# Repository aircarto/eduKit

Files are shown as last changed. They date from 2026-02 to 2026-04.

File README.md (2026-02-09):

# Kit Pedagogique CO2

Projet simple pour mesurer et afficher le CO2 en temps réel avec un ESP32.

## Materiel Necessaire

| Composant | Quantité |
|---|---|
| ESP32 DevKit V1 | 1 |
| Capteur CO2 SensAir S88 | 1 |
| Ecran OLED 0.96" SSD1306 I2C | 1 |
| Cables dupont | ~8 |
| Breadboard (optionnel) | 1 |

## Schema de Cablage

```
                    ESP32 DevKit
                  ┌──────────────┐
                  │              │
    OLED GND ─────┤ GND      VIN ├───── SensAir G+ (5V)
    OLED VDD ─────┤ 3V3      GND ├───── SensAir G0
                  │              │
    OLED SCK ─────┤ GPIO22       │
    OLED SDA ─────┤ GPIO21       │
                  │              │
SensAir TxD ──────┤ GPIO16 (RX2) │
SensAir RxD ──────┤ GPIO17 (TX2) │
                  │              │
                  └──────────────┘
```

### Details du Cablage

#### Ecran OLED SSD1306 (I2C)
| OLED | ESP32 |
|---|---|
| GND  | GND |
| VDD  | 3.3V  |
| SCK  | GPIO 22 (horloge I2C) |
| SDA  | GPIO 21 |

#### Capteur SensAir S88 (UART)
| SensAir | ESP32 |
|---|---|
| G0 | GND |
| G+ | 5V (VIN) |
| UART_TxD | GPIO 16 (RX2) |
| UART_RxD | GPIO 17 (TX2) |

> ⚠️ **ATTENTION**: Le capteur SensAir S88 fonctionne en **5V**, pas en 3.3V!
> Utilise la pin `VIN` de l'ESP32 (qui sort du 5V quand branché en USB).
> Les autres pins (Alarm_OC, PWM 1kHz, DVCC_out, etc.) ne sont pas utilisées.

## Commandes

```bash
# Compiler le projet
pio run

# Compiler et uploader
pio run -t upload

# Voir les logs série
pio device monitor
```

## Fonctionnement

1. **Au démarrage**: L'écran affiche "ATELIER PEDAGOGIQUE" avec une barre de progression
2. **Ensuite**: La valeur de CO2 s'affiche en gros avec un message selon le niveau:
   - **< 800 ppm**: "Air excellent" (bien aéré)
   - **800-1200 ppm**: "Correct" (acceptable)
   - **1200-1500 ppm**: "Aérer SVP!" (à surveiller)
   - **> 1500 ppm**: "AÉRER VITE!" (urgent)

## Structure du Projet

```
kit-pedagogique-co2/
├── platformio.ini          # Configuration PlatformIO
├── src/
│   └── main.cpp            # Code principal
├── lib/
│   └── SensAir_S88/        # Bibliothèque capteur CO2
│       ├── SensAir_S88.h
│       └── SensAir_S88.cpp
└── README.md               # Ce fichier
```

## Debug

Les logs série sont disponibles à 115200 bauds. Tu verras:
- Les valeurs CO2 toutes les 2 secondes
- Les erreurs de communication si le capteur n'est pas détecté

### Erreurs Communes

| Erreur | Cause probable |
|---|---|
| "Timeout" | Capteur non connecté ou mauvais câblage TX/RX |
| "Réponse invalide" | Interférence ou capteur défectueux |
| Valeurs aberrantes | Capteur en préchauffage (attendre 1-2 min) |

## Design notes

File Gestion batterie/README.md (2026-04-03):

# Edukit – V3

Cette V3 est une évolution du module d’alimentation conçu pour un kit éducatif.  

La carte est organisée en plusieurs blocs fonctionnels : une **entrée USB**, un **chargeur Li-ion TP4056**, une **protection batterie DW01A + FS8205A**, un **étage de load sharing**, puis un **convertisseur boost MT3608** qui génère le **5V final** pour alimenter le système éducatif.

Le principal problème de la **V2** était le suivant :  
le système fonctionnait lorsque l’USB était branché, mais **la batterie seule n’alimentait pas correctement le MT3608**, donc le kit ne pouvait pas fonctionner normalement en mode autonome.

La **V3** corrige ce comportement en mettant en place un vrai chemin d’alimentation cohérent entre :
- l’entrée USB,
- la batterie Li-ion,
- le bloc de partage de charge,
- et le convertisseur boost 5V.

### 1. USB input
L’alimentation arrive d’abord par le **connecteur micro-USB**.  
Quand un câble USB est branché, la ligne **VIN** fournit l’énergie au reste du système de gestion d’alimentation.

### 2. Battery charging
Le **TP4056** gère la recharge d’une **batterie Li-ion 1 cellule**.  
Quand l’USB est présent, il récupère le 5V d’entrée et recharge la batterie via sa broche **BAT**.  
Le courant de charge est défini par la résistance reliée à la broche **PROG**, et les deux LEDs associées au TP4056 permettent d’indiquer l’état de charge et la fin de charge.

### 3. Battery protection
La batterie ne part pas directement vers la sortie : elle passe d’abord par un **circuit de protection** composé du **DW01A** et du **FS8205A**.  
Ce bloc sert à sécuriser l’utilisation de la cellule Li-ion en protégeant contre :
- la surcharge,
- la décharge trop profonde,
- et les défauts de type surintensité ou court-circuit.

### 4. Load sharing
Le bloc de **load sharing** est la partie clé de cette V3.  
Son rôle est de gérer intelligemment la source d’énergie utilisée par le système.

En pratique :
- **si l’USB est branché**, le système peut être alimenté pendant que la batterie se recharge ;
- **si l’USB est retiré**, la batterie reprend automatiquement le relais.

Autrement dit, le kit peut être **utilisé et rechargé en même temps**, sans dépendre uniquement de la batterie lorsque l’USB est présent.

### 5. Step-up conversion to 5V
Après le bloc de partage de charge, l’alimentation attaque le **MT3608**.  
Ce composant est un **convertisseur boost** : il prend la tension disponible en entrée et l’élève pour produire une **sortie 5V stable**.

Autour du MT3608, on retrouve :
- l’inductance,
- la diode Schottky du boost,
- les condensateurs de filtrage,
- et le pont de résistances de feedback qui fixe la tension de sortie.

Le **5V obtenu** est ensuite envoyé vers le connecteur de sortie destiné à alimenter le système éducatif.

Cette architecture est intéressante pour un kit éducatif parce qu’elle montre, dans une seule carte, plusieurs fonctions essentielles de l’électronique embarquée :

- recharger une batterie Li-ion correctement,
- protéger la batterie,
- alimenter un système même pendant la charge,
- basculer automatiquement entre USB et batterie,
- et générer un 5V exploitable par un module externe.

La V3 n’est donc pas seulement une correction de la V2 : c’est une version plus aboutie, plus robuste et plus pédagogique.

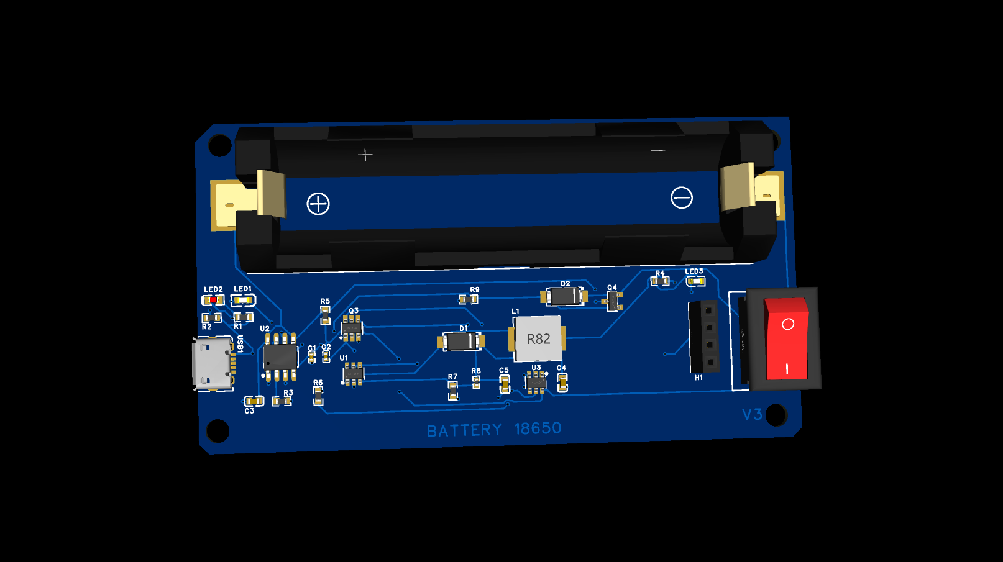
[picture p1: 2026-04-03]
Gestion batterie/3D_view.png

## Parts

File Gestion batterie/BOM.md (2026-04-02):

# BOM 

Liste des composants avec références LCSC .

| Composant | Détail  | Package | ID PCB Design | ID LCSC |
|---|---|---|---|---|
| Connecteur USB | Micro‑USB femelle, entrée charge | SMD (micro‑USB) | USB1 | C132563 |
| Résistance | 20 kΩ | 0603 | R9 | C4184 |
| Condensateur | 100 nF (découplage) | 0402 | C1, C2 | C307331 |
| Condensateur | 10 µF | 0603 | C3 | C1691 |
| Condensateur | 22 µF | 0603 | C4, C5 | C59461 |
| LED | LED bleue | 0603 | LED1 | C2987539 |
| LED | LED rouge| 0603 | LED2 | C7496810 |
| LED | LED verte | 0603 | LED3 | C2986059 |
| Résistance | 1 kΩ | 0603 | R1, R2, R4, R6 | C2907002 ||
| Résistance | 1.2 kΩ | 0603 | R3 | C2906976 |
| Résistance | 10 kΩ | 0603 | R7 | C2930027 |
| Résistance | 73.2 kΩ | 0402 | R8 | C26986 |
| Chargeur Li‑ion | TP4056 (charge 1 cellule) | ESOP-8L | U2 | C49045948 |
| MOSFET double | FS8205A (double MOSFET pour protection) | SOT‑23‑6 | Q5 | C2830320 |
| Protection Li‑ion | DW01A (IC protection 1 cellule) | SOT‑23‑6 | U3 | C351410 |
| Diode Schottky | SS34 (redressement / protection) | SMA | D1, D2 | C22448055 |
| Résistance | 100 Ω | 0603 | R5 | C2906981 |
| MOSFET P‑channel | DMP1045U‑7 | SOT‑23 | Q4 | C177033 |
| Support batterie | Support/porte‑pile 18650 | THT / mécanique | BT1 | C2988620 |
| Interrupteur | Slide switch (ON/OFF) | SMD | SW1 | C6917318 |
| Inductance | 22 µH (boost) | SMD 7x6.6mm | L1 | C177244 |
| Convertisseur boost | MT3608 (step‑up) | SOT‑23‑6 | U1 | C84817 |
| Header | Header femelle 1×4, pas 2.54 mm | THT 2.54 mm | H1 | C5116530 |

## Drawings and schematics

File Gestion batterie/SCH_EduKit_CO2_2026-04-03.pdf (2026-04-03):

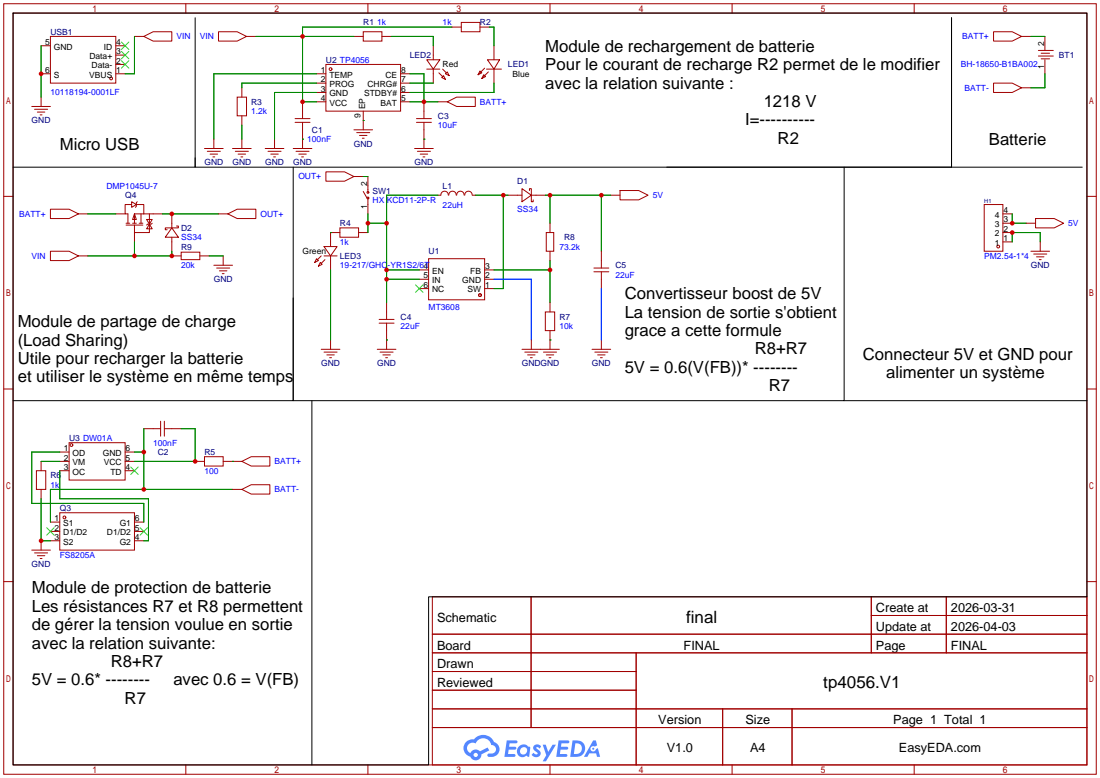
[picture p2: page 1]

Module de rechargement de batterie
Pour le courant de recharge R2 permet de le modifier
Blue
avec la relation suivante :

Convertisseur boost de 5V
La tension de sortie s'obtient
grace a cette formule

Module de partage de charge
(Load Sharing)
Utile pour recharger la batterie
et utiliser le système en même temps

Connecteur 5V et GND pour
alimenter un système

GND
Module de protection de batterie
Les résistances R7 et R8 permettent
de gérer la tension voulue en sortie
avec la relation suivante:
5V = 0.6* -------- avec 0.6 = V(FB)

Schematic | final | Create at | 2026-03-31

Update at | 2026-04-03

Board | FINAL | Page | FINAL
Drawn | | tp4056.V1
Reviewed

Version | Size | Page 1 Total 1
V1.0 | A4 | EasyEDA.com

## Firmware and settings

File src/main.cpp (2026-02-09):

/**
 * ============================================
 *         KIT PEDAGOGIQUE CO2
 * ============================================
 *
 * Materiel:
 *   - Raspberry Pi Pico 2 W
 *   - Capteur CO2 SensAir S88
 *   - Ecran OLED 0.96" SSD1306 (I2C, bicolore jaune/bleu)
 *
 * Cablage:
 *   OLED:
 *     - GND  -> GND
 *     - VDD  -> 3.3V
 *     - SCL  -> GPIO 5 (I2C0 SCL)
 *     - SDA  -> GPIO 4 (I2C0 SDA)
 *
 *   SensAir S88:
 *     - G0       -> GND
 *     - G+       -> VBUS (5V)
 *     - UART_TxD -> GPIO 1 (UART0 RX)
 *     - UART_RxD -> GPIO 0 (UART0 TX)
 *
 * Note: Le capteur S88 utilise le protocole Modbus RTU a 9600 bauds.
 *
 * OLED bicolore: les 16 premiers pixels (y 0-15) sont jaunes,
 * le reste (y 16-63) est bleu. Le layout est optimise en consequence.
 */

#include "SensAir_S88.h"
#include "ble_provisioning.h"
#include "pico_compat.h"
#include <Arduino.h>
#include <HTTPClient.h>
#include <SSD1306Wire.h>
#include <WiFi.h>
#include <Wire.h>
#include <pico/unique_id.h>

// ============================================
// CONFIGURATION SERVEUR
// ============================================

const char *ENDPOINT_URL =
    "https://data.moduleair.fr/eduKit/edukit_endpoint.php";

const char *GET_PUBLIC_NAME_URL =
    "https://api.aircarto.fr/capteurs/getPublicName.php";

// Identifiant unique du capteur
String deviceId = "";

// Nom public du capteur (recupere depuis le serveur)
String publicName = "";

// Configuration WiFi (chargee depuis NVS)
String wifiSSID = "airlabo";
String wifiPassword = "xxxxxx";

// ============================================
// CONFIGURATION DES PINS
// ============================================

#define OLED_SDA 4
#define OLED_SCL 5
#define OLED_ADDRESS 0x3C

#define S88_RX 1 // GPIO1 = UART0 RX
#define S88_TX 0 // GPIO0 = UART0 TX

// ============================================
// CONFIGURATION
// ============================================

#define CO2_READ_INTERVAL 2000

// Seuils de CO2
#define CO2_GOOD 800
#define CO2_BAD 1500

// ============================================
// MACHINE A ETATS
// ============================================

enum AppState { STATE_BLE_PROVISIONING, STATE_NORMAL };

AppState currentState = STATE_BLE_PROVISIONING;

// ============================================
// OBJETS GLOBAUX
// ============================================

SSD1306Wire display(OLED_ADDRESS, OLED_SDA, OLED_SCL);
SensAir_S88 co2Sensor;

// Variables
int currentCO2 = 0;
unsigned long lastCO2Read = 0;
unsigned long lastDataSend = 0;
unsigned long lastDisplayUpdate = 0;
uint32_t co2Sum = 0;
uint16_t co2SampleCount = 0;
bool sensorReady = false;
bool wifiConnected = false;

// ============================================
// ECRAN DE CHARGEMENT
// ============================================

void showLoadingScreen() {
  int progressBarWidth = 100;
  int progressBarHeight = 10;
  int progressBarX = (128 - progressBarWidth) / 2;
  int progressBarY = 40;

  for (int progress = 0; progress <= 100; progress += 2) {
    display.clear();

    // Zone jaune (0-15): titre
    display.setFont(ArialMT_Plain_10);
    display.setTextAlignment(TEXT_ALIGN_CENTER);
    display.drawString(64, 2, "ATELIER PEDAGOGIQUE");

    // Zone bleue (16-63): barre de progression
    display.drawRect(progressBarX, progressBarY, progressBarWidth,
                     progressBarHeight);

    int fillWidth = (progress * (progressBarWidth - 4)) / 100;
    display.fillRect(progressBarX + 2, progressBarY + 2, fillWidth,
                     progressBarHeight - 4);

    display.setFont(ArialMT_Plain_10);
    display.drawString(64, 52, String(progress) + "%");

    display.display();
    delay(100);
  }
}

// ============================================
// GENERATION DEVICE ID
// ============================================

void generateDeviceId() {
  pico_unique_board_id_t id;
  pico_get_unique_board_id(&id);

  deviceId = "";
  for (int i = 0; i < PICO_UNIQUE_BOARD_ID_SIZE_BYTES; i++) {
    char buf[3];
    sprintf(buf, "%02X", id.id[i]);
    deviceId += buf;
  }
  Serial.printf("Device ID (Pico ID): %s\n", deviceId.c_str());
}

// ============================================
// CONNEXION WIFI
// ============================================

void displayWiFiConnecting(const String &ssid) {
  display.clear();

  // Zone jaune (0-15): titre
  display.setFont(ArialMT_Plain_10);
  display.setTextAlignment(TEXT_ALIGN_CENTER);
  display.drawString(64, 2, "Connexion WiFi");

  // Zone bleue (16-63): SSID
  display.setFont(ArialMT_Plain_16);
  display.drawString(64, 24, ssid);
  display.setFont(ArialMT_Plain_10);
  display.drawString(64, 48, "Veuillez patienter...");
  display.display();
}

void displayWiFiStatus(bool connected) {
  display.clear();

  // Zone jaune (0-15): titre
  display.setFont(ArialMT_Plain_10);
  display.setTextAlignment(TEXT_ALIGN_CENTER);
  display.drawString(64, 2, "WiFi");

  // Zone bleue (16-63): statut
  display.setFont(ArialMT_Plain_16);
  display.setTextAlignment(TEXT_ALIGN_CENTER);
  if (connected) {
    display.drawString(64, 22, "Connexion");
    display.drawString(64, 40, "etablie");
  } else {
    display.drawString(64, 22, "Connexion");
    display.drawString(64, 40, "echouee");
  }
  display.display();
  delay(connected ? 800 : 2000);
}

bool connectWiFi() {
  Serial.printf("Connexion au WiFi: %s\n", wifiSSID.c_str());
  displayWiFiConnecting(wifiSSID);

  WiFi.mode(WIFI_STA);
  WiFi.begin(wifiSSID.c_str(), wifiPassword.c_str());

  int attempts = 0;
  while (WiFi.status() != WL_CONNECTED && attempts < 120) {
    delay(500);
    Serial.print(".");
    attempts++;
  }
  Serial.println();

  if (WiFi.status() == WL_CONNECTED) {
    Serial.printf("WiFi connecte! IP: %s\n", WiFi.localIP().toString().c_str());
    Serial.printf("Signal WiFi: %d dBm\n", WiFi.RSSI());
    wifiConnected = true;
    displayWiFiStatus(true);
    return true;
  } else {
    Serial.println("Echec connexion WiFi!");
    wifiConnected = false;
    displayWiFiStatus(false);
    return false;
  }
}

// ============================================
// RECUPERATION DU NOM PUBLIC
// ============================================

bool fetchPublicName() {
  if (!wifiConnected || WiFi.status() != WL_CONNECTED) {
    Serial.println("[API] WiFi non connecte");
    return false;
  }

  HTTPClient http;
  WiFiClientSecure client;
  client.setInsecure();

  String url = String(GET_PUBLIC_NAME_URL) + "?device_id=" + deviceId;

  Serial.println("[API] Recuperation du nom public...");
  Serial.println("[API] URL: " + url);

  http.begin(client, url);
  http.addHeader("Content-Type", "application/json");

  int httpCode = http.GET();

  if (httpCode == 200) {
    String response = http.getString();
    Serial.println("[API] Reponse: " + response);

    int startIdx = response.indexOf("\"public_name\":");
    if (startIdx != -1) {
      startIdx += 14;
      while (startIdx < (int)response.length() &&
             (response[startIdx] == ' ' || response[startIdx] == '"')) {
        startIdx++;
      }
      int endIdx = response.indexOf("\"", startIdx);
      if (endIdx != -1) {
        publicName = response.substring(startIdx, endIdx);
        Serial.println("[API] Nom public recupere: " + publicName);

        Preferences prefs;
        prefs.begin("edukit", false);
        prefs.putString("public_name", publicName);
        prefs.end();

        http.end();
        return true;
      }
    }
    Serial.println("[API] ERREUR: Impossible de parser le nom public");
  } else {
    Serial.printf("[API] ERREUR: Code HTTP %d\n", httpCode);
  }

  http.end();
  return false;
}

void loadPublicNameFromNVS() {
  Preferences prefs;
  prefs.begin("edukit", true);
  publicName = prefs.getString("public_name", "");
  prefs.end();

  if (publicName.length() > 0) {
    Serial.println("[NVS] Nom public charge: " + publicName);
  } else {
    Serial.println("[NVS] Pas de nom public stocke");
  }
}

// ============================================
// ENVOI DES DONNEES AU SERVEUR
// ============================================

String lastHttpError = "";

String getHttpErrorMessage(int code) {
  switch (code) {
  case 200:
    return "OK";
  case 400:
    return "Capteur inconnu";
  case 401:
    return "JSON invalide";
  case 500:
    return "Erreur serveur";
  case -1:
    return "Connexion echouee";
  case -2:
    return "Envoi echoue";
  case -3:
    return "Timeout";
  case -4:
    return "Pas de reponse";
  case -5:
    return "Connexion perdue";
  case -6:
    return "WiFi deconnecte";
  default:
    if (code < 0)
      return "Erreur reseau";
    if (code >= 500)
      return "Erreur serveur";
    if (code >= 400)
      return "Erreur requete";
    return "Erreur inconnue";
  }
}

int sendDataToServer(int co2Value) {
  if (!wifiConnected || WiFi.status() != WL_CONNECTED) {
    Serial.println("[HTTP] WiFi non connecte, tentative de reconnexion...");
    if (!connectWiFi()) {
      Serial.println("[HTTP] ERREUR: Impossible de se reconnecter au WiFi");
      return -6;
    }
  }

  HTTPClient http;
  WiFiClientSecure client;
  client.setInsecure();

  Serial.println("[HTTP] ================================");
  Serial.printf("[HTTP] Envoi des donnees a %s\n", ENDPOINT_URL);

  String jsonPayload = "{";
  jsonPayload += "\"device_id\":\"" + deviceId + "\",";
  jsonPayload += "\"signal_quality\":" + String(WiFi.RSSI()) + ",";
  jsonPayload += "\"co2\":" + String(co2Value);
  jsonPayload += "}";

  Serial.printf("[HTTP] Payload: %s\n", jsonPayload.c_str());

  http.begin(client, ENDPOINT_URL);
  http.addHeader("Content-Type", "application/json");
  http.setTimeout(10000);

  int httpResponseCode = http.POST(jsonPayload);

  if (httpResponseCode > 0) {
    String response = http.getString();
    Serial.printf("[HTTP] Code reponse: %d\n", httpResponseCode);
    Serial.println("[HTTP] === REPONSE SERVEUR ===");
    Serial.println(response);
    Serial.println("[HTTP] === FIN REPONSE ===");

    if (httpResponseCode == 200) {
      Serial.println("[HTTP] SUCCESS: Donnees enregistrees!");
    } else if (httpResponseCode == 400) {
      Serial.println("[HTTP] ERREUR 400: Capteur inconnu");
    } else if (httpResponseCode == 401) {
      Serial.println("[HTTP] ERREUR 401: Requete invalide");
    } else if (httpResponseCode == 500) {
      Serial.println("[HTTP] ERREUR 500: Erreur serveur");
    }
  } else {
    Serial.printf("[HTTP] ERREUR CONNEXION (code %d)\n", httpResponseCode);
  }

  Serial.println("[HTTP] ================================");
  http.end();
  return httpResponseCode;
}

// ============================================
// AFFICHAGE DU CO2
// ============================================

const char *getCO2Message(int co2) {
  if (co2 > -1 && co2 < CO2_GOOD)
    return "BIEN";
  if (co2 >= CO2_GOOD && co2 < CO2_BAD)
    return "AERER SVP";
  if (co2 >= CO2_BAD)
    return "AERER SVP";
  return "ERREUR";
}

void drawWiFiBarsWithLevel(int level, bool crossed) {
  const int barCount = 3;
  const int barWidth = 3;
  const int barSpacing = 1;
  const int barHeights[barCount] = {4, 8, 12};
  const int bottomY = 14;
  const int totalWidth = barCount * barWidth + (barCount - 1) * barSpacing;
  const int startX = 128 - 1 - totalWidth;
  const int maxHeight = barHeights[barCount - 1];

  for (int i = 0; i < barCount; i++) {
    int h = barHeights[i];
    int x = startX + i * (barWidth + barSpacing);
    int y = bottomY - h;
    if (level > i) {
      display.fillRect(x, y, barWidth, h);
    } else {
      display.drawRect(x, y, barWidth, h);
    }
  }

  if (crossed) {
    const int extend = 1;
    int x0 = startX - extend;
    int y0 = bottomY;
    int x1 = startX + totalWidth - 1 + extend;
    int y1 = bottomY - maxHeight;

    // Thicker, longer single slash over the bars
    display.drawLine(x0, y1, x1, y0);
    display.drawLine(x0 + 1, y1, x1 + 1, y0);
  }
}

void drawWiFiBars(int rssi) {
  int level = 0;
  if (rssi > -55)
    level = 3;
  else if (rssi > -70)
    level = 2;
  else if (rssi > -85)
    level = 1;

  drawWiFiBarsWithLevel(level, false);
}

void drawWiFiBarsDisconnected() { drawWiFiBarsWithLevel(0, true); }

void displayCO2(int co2) {
  display.clear();

  // Zone jaune (y 0-15): header avec "CO2 (ppm)" et indicateur WiFi
  display.setFont(ArialMT_Plain_10);
  display.setTextAlignment(TEXT_ALIGN_LEFT);
  display.drawString(0, 2, "CO2");

  // Indicateur WiFi en haut a droite (zone jaune)
  if (wifiConnected && WiFi.status() == WL_CONNECTED) {
    drawWiFiBars(WiFi.RSSI());
  } else {
    display.setTextAlignment(TEXT_ALIGN_RIGHT);
    display.drawString(128, 2, "OFFLINE");
  }

  // Zone bleue (y 16-63): valeur CO2 + message
  const int valueY = 18;
  display.setFont(ArialMT_Plain_24);
  display.setTextAlignment(TEXT_ALIGN_CENTER);

  if (co2 > 0) {
    display.drawString(64, valueY, String(co2));

    // "ppm" aligned with the digits like in offline mode
    const int ppmY = valueY + (24 - 10) / 2;
    display.setFont(ArialMT_Plain_10);
    display.setTextAlignment(TEXT_ALIGN_LEFT);
    display.drawString(96, ppmY, "ppm");

    display.setFont(ArialMT_Plain_16);
    display.setTextAlignment(TEXT_ALIGN_CENTER);
    display.drawString(64, 46, getCO2Message(co2));
  } else {
    display.setFont(ArialMT_Plain_16);
    display.setTextAlignment(TEXT_ALIGN_CENTER);
    display.drawString(64, 20, "Branchements");
    display.drawString(64, 40, "incorrects");
  }

  display.display();
}

void displayBLEProvisioning(int co2) {
  display.clear();

  // Zone jaune (y 0-15): titre
  display.setFont(ArialMT_Plain_10);
  display.setTextAlignment(TEXT_ALIGN_LEFT);
  display.drawString(0, 2, "CO2");
  drawWiFiBarsDisconnected();

  // Zone bleue (y 16-63): CO2 en grand + info configuration
  const int valueY = 18;
  display.setFont(ArialMT_Plain_24);
  display.setTextAlignment(TEXT_ALIGN_CENTER);
  if (co2 > 0) {
    display.drawString(64, valueY, String(co2));

    // Align "ppm" vertically with the digits by centering it on the value.
    const int ppmY = valueY + (24 - 10) / 2;
    display.setFont(ArialMT_Plain_10);
    display.setTextAlignment(TEXT_ALIGN_LEFT);
    display.drawString(96, ppmY, "ppm");

    display.setTextAlignment(TEXT_ALIGN_CENTER);
    display.drawString(64, 54, getCO2Message(co2));
  } else {
    display.setFont(ArialMT_Plain_16);
    display.setTextAlignment(TEXT_ALIGN_CENTER);
    display.drawString(64, 20, "Branchements");
    display.drawString(64, 40, "incorrects");
  }

  display.display();
}

void displayError(const char *message) {
  display.clear();

  // Zone jaune (y 0-15): titre erreur
  display.setFont(ArialMT_Plain_10);
  display.setTextAlignment(TEXT_ALIGN_CENTER);
  display.drawString(64, 2, "ERREUR");

  // Zone bleue (y 16-63): message
  display.setFont(ArialMT_Plain_10);
  display.drawString(64, 30, message);
  display.display();
}

// ============================================
// LECTURE DU CAPTEUR
// ============================================

void readCO2Sensor() {
  int co2Value = co2Sensor.getCO2();

  if (co2Value > 0) {
    currentCO2 = co2Value;
    sensorReady = true;
    Serial.printf("CO2: %d ppm\n", currentCO2);

    // Mettre a jour la valeur BLE
    updateBLECO2Value(currentCO2);

    // Accumuler pour la moyenne d'envoi
    co2Sum += (uint32_t)co2Value;
    co2SampleCount++;
  } else {
    uint8_t error = co2Sensor.getLastError();
    Serial.printf("Erreur lecture CO2: %d\n", error);

    switch (error) {
    case 1:
      Serial.println("  -> Port serie non initialise");
      break;
    case 2:
      Serial.println("  -> Timeout (capteur non connecte?)");
      break;
    case 3:
      Serial.println("  -> Reponse invalide");
      break;
    }
  }
}

// ============================================
// GESTION WiFi PROVISIONING
// ============================================

void handleWiFiConfigReceived() {
  String ssid = getReceivedSSID();
  String password = getReceivedPassword();
  clearReceivedWiFiConfig();

  Serial.printf("[PROV] Tentative de connexion a: %s\n", ssid.c_str());
  updateBLEStatus(PROV_CONNECTING);

  // Afficher sur l'ecran
  displayWiFiConnecting(ssid);

  // Stocker temporairement
  wifiSSID = ssid;
  wifiPassword = password;

  if (connectWiFi()) {
    // Succes: sauvegarder et passer en mode normal
    updateBLEStatus(PROV_CONNECTED);
    saveWiFiConfig(ssid, password);

    // Recuperer le nom public
    loadPublicNameFromNVS();
    if (publicName.length() == 0) {
      fetchPublicName();
    }

    // Attendre que l'app lise le statut mis a jour
    delay(3000);

    // Passer en mode normal
    stopBLE();
    delay(500);

    // Redemarrer BLE en mode config
    initBLEConfigMode(deviceId);

    currentState = STATE_NORMAL;
    Serial.println("[PROV] -> STATE_NORMAL");

    // Demarrer le timer d'envoi (pas d'envoi immediat)
    lastDataSend = millis();
    co2Sum = 0;
    co2SampleCount = 0;
  } else {
    // Echec: rester en provisioning
    if (WiFi.status() == WL_CONNECT_FAILED) {
      updateBLEStatus(PROV_WRONG_PASSWORD);
    } else {
      updateBLEStatus(PROV_FAILED);
    }

    Serial.println("[PROV] Echec WiFi, retour au provisioning");
    delay(2000);
    updateBLEStatus(PROV_IDLE);
  }
}

// ============================================
// SETUP
// ============================================

void setup() {
  Serial.begin(115200);
  delay(2000);
  Serial.println();
  Serial.println("================================");
  Serial.println("   KIT PEDAGOGIQUE CO2");
  Serial.println("   (Raspberry Pi Pico 2 W)");
  Serial.println("================================");
  Serial.println();

  // 1. Init I2C et OLED
  Wire.setSDA(OLED_SDA);
  Wire.setSCL(OLED_SCL);
  Wire.begin();

  Serial.println("Initialisation de l'ecran OLED...");
  display.init();
  display.flipScreenVertically();
  display.setContrast(255);

  // 2. Ecran de chargement
  showLoadingScreen();

  // 3. Generer deviceId
  generateDeviceId();

  // 4. Charger refreshRate depuis NVS
  int rate = loadRefreshRateFromNVS();
  Serial.printf("Refresh rate: %d secondes\n", rate);

  // 5. Init capteur CO2
  Serial.println("Initialisation du capteur CO2...");
  Serial1.setRX(S88_RX);
  Serial1.setTX(S88_TX);
  Serial1.begin(9600);
  co2Sensor.begin(Serial1);
  delay(1000);

  Serial.println("Premiere lecture du capteur...");
  readCO2Sensor();

  // 6. Verifier NVS pour credentials WiFi
  if (getStoredWiFiConfig(wifiSSID, wifiPassword)) {
    // Credentials trouvees, tenter connexion
    Serial.println("Credentials WiFi trouvees, tentative de connexion...");

    if (connectWiFi()) {
      // Connecte -> mode NORMAL
      currentState = STATE_NORMAL;
      Serial.println("-> STATE_NORMAL");

      // Recuperer/charger le nom public
      loadPublicNameFromNVS();
      if (publicName.length() == 0) {
        fetchPublicName();
      }

      // Demarrer le timer d'envoi (pas d'envoi immediat)
      lastDataSend = millis();
      co2Sum = 0;
      co2SampleCount = 0;

      // Demarrer BLE en mode config (arriere-plan)
      initBLEConfigMode(deviceId);
    } else {
      // Echec WiFi -> mode provisioning
      currentState = STATE_BLE_PROVISIONING;
      Serial.println("Echec WiFi -> STATE_BLE_PROVISIONING");
      initBLEProvisioning(deviceId);
    }
  } else {
    // Pas de credentials -> mode provisioning
    currentState = STATE_BLE_PROVISIONING;
    Serial.println("Pas de config WiFi -> STATE_BLE_PROVISIONING");
    initBLEProvisioning(deviceId);
  }

  Serial.println();
  Serial.println("Systeme pret!");
  if (publicName.length() > 0) {
    Serial.println("Nom public: " + publicName);
  }
  Serial.println();
}

// ============================================
// LOOP
// ============================================

void loop() {
  unsigned long currentTime = millis();

  // Traitement BLE (toujours actif)
  processBLE();

  // Lecture CO2 periodique (dans tous les modes)
  if (currentTime - lastCO2Read >= CO2_READ_INTERVAL) {
    lastCO2Read = currentTime;
    readCO2Sensor();
  }

  switch (currentState) {

  case STATE_BLE_PROVISIONING:
    // Verifier si config WiFi recue via BLE
    if (hasReceivedWiFiConfig()) {
      handleWiFiConfigReceived();
    }

    // Affichage BLE provisioning
    if (currentTime - lastDisplayUpdate >= 500) {
      lastDisplayUpdate = currentTime;
      displayBLEProvisioning(currentCO2);
    }
    break;

  case STATE_NORMAL:
    // Verifier changement de refresh rate via BLE
    if (checkAndResetRefreshRateChanged()) {
      Serial.printf("[MAIN] Refresh rate mis a jour: %d s\n",
                    getRefreshRateSeconds());
    }

    // Verifier si config WiFi recue via BLE (reconfig)
    if (hasReceivedWiFiConfig()) {
      handleWiFiConfigReceived();
    }

    // Envoi periodique au serveur
    if (sensorReady && wifiConnected &&
        (currentTime - lastDataSend >= getRefreshRateMs())) {
      lastDataSend = currentTime;
      int co2ToSend =
          (co2SampleCount > 0) ? (int)(co2Sum / co2SampleCount) : currentCO2;
      sendDataToServer(co2ToSend);
      co2Sum = 0;
      co2SampleCount = 0;
    }

    // Affichage CO2
    if (currentTime - lastDisplayUpdate >= 500) {
      lastDisplayUpdate = currentTime;
      if (sensorReady) {
        displayCO2(currentCO2);
      } else {
        displayError("Capteur non detecte");
      }
    }
    break;
  }

  delay(10);
}

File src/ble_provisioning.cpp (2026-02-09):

/**
 * ============================================
 *    BLE PROVISIONING - Implementation BTstackLib
 * ============================================
 *
 * Implementation pour Raspberry Pi Pico W utilisant BTstackLib.
 */

#include "ble_provisioning.h"
#include "pico_compat.h"

#include <BTstackLib.h>
#include <WiFi.h>
#include <pico/unique_id.h>

// Include direct de l'API C BTstack pour les notifications
extern "C" {
#include "ble/att_server.h"
}

// ============================================
// Characteristic IDs (pour dispatch callbacks)
// ============================================

#define CHARID_DEVICE_INFO    0
#define CHARID_WIFI_NETWORKS  1
#define CHARID_WIFI_CONFIG    2
#define CHARID_STATUS         3
#define CHARID_CO2_DATA       4
#define CHARID_SETTINGS       5

// ============================================
// Etat interne
// ============================================

static bool bleActive = false;
static bool bleProvisioningMode = false; // true = provisioning, false = config
static bool clientConnected = false;
static hci_con_handle_t connectionHandle = HCI_CON_HANDLE_INVALID;

// Value handles retournes par addGATTCharacteristicDynamic
static uint16_t handleDeviceInfo = 0;
static uint16_t handleWifiNetworks = 0;
static uint16_t handleWifiConfig = 0;
static uint16_t handleStatus = 0;
static uint16_t handleCO2Data = 0;
static uint16_t handleSettings = 0;

// Donnees BLE
static String bleDeviceName = "";
static String bleDeviceId = "";
static String cachedDeviceInfoJson = "";
static String cachedWifiNetworksJson = "";
static String cachedStatusStr = "0";
static String cachedCO2Str = "0";
static String cachedSettingsJson = "{\"refreshRate\":60}";

// Config WiFi recue
static bool wifiConfigReceived = false;
static String receivedSSID = "";
static String receivedPassword = "";

// Settings
static int refreshRateSeconds = 60;
static bool refreshRateChanged = false;

// NVS
static Preferences nvs;

// ============================================
// Fonctions utilitaires internes
// ============================================

static String generateDeviceInfoJson(const String &publicName) {
  String json = "{\"chipId\":\"" + bleDeviceId + "\",";
  json += "\"version\":\"EduKit-v1.0\",";
  if (publicName.length() > 0) {
    json += "\"publicName\":\"" + publicName + "\"";
  } else {
    json += "\"publicName\":\"" + bleDeviceName + "\"";
  }
  json += "}";
  return json;
}

static void scanWiFiNetworks() {
  Serial.println("[BLE] Scan des reseaux WiFi...");
  int n = WiFi.scanNetworks();

  String json = "[";
  for (int i = 0; i < n && i < 10; i++) {
    if (i > 0) json += ",";
    json += "{\"s\":\"";
    json += WiFi.SSID(i);
    json += "\",\"r\":";
    json += String(WiFi.RSSI(i));
    json += ",\"e\":";
    json += String(WiFi.encryptionType(i) != ENC_TYPE_NONE ? 1 : 0);
    json += "}";
  }
  json += "]";

  WiFi.scanDelete();
  cachedWifiNetworksJson = json;
  Serial.printf("[BLE] %d reseaux trouves\n", n);
}

static void parseWiFiConfig(uint8_t *buffer, uint16_t size) {
  String value = "";
  for (uint16_t i = 0; i < size; i++) {
    value += (char)buffer[i];
  }
  Serial.println("[BLE] WiFi config recue");

  int ssidStart = value.indexOf("\"ssid\":\"");
  int pwdStart = value.indexOf("\"password\":\"");

  if (ssidStart != -1 && pwdStart != -1) {
    ssidStart += 8;
    int ssidEnd = value.indexOf("\"", ssidStart);
    receivedSSID = value.substring(ssidStart, ssidEnd);

    pwdStart += 12;
    int pwdEnd = value.indexOf("\"", pwdStart);
    receivedPassword = value.substring(pwdStart, pwdEnd);

    Serial.printf("[BLE] SSID: %s\n", receivedSSID.c_str());
    Serial.println("[BLE] Password: ********");

    wifiConfigReceived = true;
  } else {
    Serial.println("[BLE] Format JSON invalide");
  }
}

static void parseSettingsConfig(uint8_t *buffer, uint16_t size) {
  String value = "";
  for (uint16_t i = 0; i < size; i++) {
    value += (char)buffer[i];
  }
  Serial.println("[BLE] Settings config recue: " + value);

  int rateStart = value.indexOf("\"refreshRate\":");
  if (rateStart != -1) {
    rateStart += 14;
    int rateEnd = rateStart;
    while (rateEnd < (int)value.length() && value[rateEnd] >= '0' &&
           value[rateEnd] <= '9') {
      rateEnd++;
    }

    if (rateEnd > rateStart) {
      int newRate = value.substring(rateStart, rateEnd).toInt();

      if (newRate == 10 || newRate == 30 || newRate == 60) {
        refreshRateSeconds = newRate;
        refreshRateChanged = true;
        cachedSettingsJson = "{\"refreshRate\":" + String(refreshRateSeconds) + "}";
        Serial.printf("[BLE] Nouveau refresh rate: %d secondes\n", refreshRateSeconds);

        Preferences prefs;
        prefs.begin("edukit", false);
        prefs.putInt("refresh_rate", refreshRateSeconds);
        prefs.end();
        Serial.println("[NVS] Refresh rate sauvegarde");
      } else {
        Serial.printf("[BLE] Valeur invalide: %d (doit etre 10, 30 ou 60)\n", newRate);
      }
    }
  } else {
    Serial.println("[BLE] Format JSON invalide pour settings");
  }
}

// ============================================
// Callbacks BTstackLib
// ============================================

static void deviceConnectedCallback(BLEStatus status, BLEDevice *device) {
  if (status == BLE_STATUS_OK) {
    clientConnected = true;
    connectionHandle = device->getHandle();
    Serial.println("[BLE] Client connecte");
  }
}

static void deviceDisconnectedCallback(BLEDevice *device) {
  (void)device;
  clientConnected = false;
  connectionHandle = HCI_CON_HANDLE_INVALID;
  Serial.println("[BLE] Client deconnecte");
  BTstack.startAdvertising();
}

static uint16_t gattReadCallback(uint16_t value_handle, uint8_t *buffer, uint16_t buffer_size) {
  const char *data = nullptr;
  uint16_t data_len = 0;

  if (value_handle == handleDeviceInfo) {
    data = cachedDeviceInfoJson.c_str();
    data_len = cachedDeviceInfoJson.length();
  } else if (value_handle == handleWifiNetworks) {
    data = cachedWifiNetworksJson.c_str();
    data_len = cachedWifiNetworksJson.length();
  } else if (value_handle == handleStatus) {
    data = cachedStatusStr.c_str();
    data_len = cachedStatusStr.length();
  } else if (value_handle == handleCO2Data) {
    data = cachedCO2Str.c_str();
    data_len = cachedCO2Str.length();
  } else if (value_handle == handleSettings) {
    data = cachedSettingsJson.c_str();
    data_len = cachedSettingsJson.length();
  } else {
    return 0;
  }

  if (buffer) {
    uint16_t copy_len = (data_len < buffer_size) ? data_len : buffer_size;
    memcpy(buffer, data, copy_len);
    return copy_len;
  }
  return data_len;
}

static int gattWriteCallback(uint16_t value_handle, uint8_t *buffer, uint16_t size) {
  if (value_handle == handleWifiConfig) {
    parseWiFiConfig(buffer, size);
    return 0;
  } else if (value_handle == handleSettings) {
    parseSettingsConfig(buffer, size);
    return 0;
  }
  return 0;
}
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

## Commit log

2026-02-09 refactor: overhaul BLE provisioning to a structured API for Pico W, add CO2 and settings characteristics, and generalize SensAir_S88 serial interface.
    [kit-pedagogique-co2.kicad_pcb, kit-pedagogique-co2.kicad_sch]
2026-03-05 Update BOM with component details and corrections
2026-10-30 feat: configuration WiFi par Bluetooth (Improv WiFi) portée de l'Alba
    - Ajout de src/ble_improv.{h,cpp} : provisioning BLE non bloquant, même
    dialecte Improv que ModuleAir_V4 / mini / Alba
    - platformio.ini : plateforme épinglée (aa70b80, GCC 14), cœur arduino-pico
    5.6.0, WiFi + Bluetooth activés
    - pico_compat.h : Preferences::remove()
    - main.cpp et README mis à jour
2026-11-03 feat: LED du Pico allumée au démarrage, témoin d'alimentation
    Les élèves câblent eux-mêmes l'EduKit : la LED de la carte s'allume dès
    le début de setup() pour montrer que le 5V et le GND sont bien branchés.
    Sur le Pico 2 W elle est reliée à la puce CYW43, pilotée par LED_BUILTIN.
2026-11-03 feat: version du firmware dans include/version.h, envoyée au serveur
    La version (2.1.0) vit dans include/version.h, avec un CHANGELOG.md.
    Chaque mesure envoie "firmware_version", que edukit_endpoint.php écrit
    dans capteurs.firmware_version (gardée si absente ou mal formée). La
    version s'affiche aussi sur l'écran de démarrage.
2026-11-03 feat: firmware en anglais (pico_en) et capteur BME280 optionnel
    - Textes de l'écran dans include/lang.h, en français par défaut ou en
    anglais avec l'environnement PlatformIO pico_en (-DLANG_EN).
    - Version du firmware sous la barre de progression au démarrage.
    - BME280 optionnel sur I2C1 (GPIO 6 SDA, GPIO 7 SCL) : température,
    humidité et pression, affichées en alternance avec le CO2 et envoyées
    au serveur, que edukit_endpoint.php écrit dans InfluxDB.
2026-11-03 fix: identité au démarrage affichée après la détection du BME280
2026-11-03 WiFi : plusieurs essais au demarrage, "CO2" a cote de ppm, doc
    - Demarrage : jusqu'a 4 essais de connexion WiFi en 30 s (beginNoBlock,
    deconnexion entre deux essais). Le premier essai echouait une fois
    sur deux apres un reboot (statut 4) et le kit passait en Bluetooth
    pour 10 minutes. Logs d'echec plus clairs.
    - Ecran avec BME280 : "CO2" a la hauteur de "ppm", virgule decimale en FR.
    - README : pas de temps d'affichage et d'envoi, BME280 6 broches.
    - docs/ : rendu de l'ecran (FR/EN) et schema de cablage Dupont.
    - plaque_edukit.png : photo de la plaque.
    Claude-Session: https://claude.ai/code/session_01M1LDkBKCDZfyaFEwZiM1Zu
2026-11-04 chore: version 2.1.1 (plusieurs essais WiFi au demarrage)
    La correction WiFi et l'affichage "CO2" a cote de ppm etaient notes
    dans la section 2.1.0 du CHANGELOG : ils passent dans une section 2.1.1.
2026-11-04 feat: scan WiFi avant connexion, Bluetooth plus vite hors reseau (2.1.2)
    Le driver CYW43 renvoie le statut 4 (refuse) aussi pour un reseau absent :
    avec un SSID inexistant, les 4 essais prenaient ~14 s avant le Bluetooth.
    - Demarrage : scan (~1 s) avant les essais. Reseau absent de deux scans :
    un seul essai (reseau masque eventuel) au lieu de 4.
    - Hors ligne : l'essai toutes les 10 min est saute si le reseau n'est pas
    a portee.
    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
2026-11-05 docs: tutoriel de montage illustré en 3D (scène, rendus, visionneuse)
    - docs/tuto : scène three.js de la plaque (STL) et des cartes, câblage,
    étapes, rendus headless (npm run render) et publier.sh vers le site
    (aircarto.fr/eduKit_co2/tuto.html, tuto-en.html et 3d/). Les images
    générées ne sont pas versionnées.
    - Plaque de montage (STL) et captures des cartes rangées dans docs/.
    - README : le S88 s'alimente sur le rail 5V de la carte support (VSYS,
    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
